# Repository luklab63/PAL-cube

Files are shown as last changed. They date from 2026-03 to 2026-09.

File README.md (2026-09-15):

# PAL V2 

## electronics 

* ESP32 C6 dev-module
* 2x SG90 servo moteurs 
* SH1106 0.94" OLED screen 
* power switch 
* small battery bank 
* used usb cable 
* PCB 
* 2 LEDs + 2x 220ohm resistors 

## The PCB 

it is a simple PCB that holds the ESP32 the battery connector and the screen and servo connectors. it is 70 x 60 mm. two 3mm LEDs 

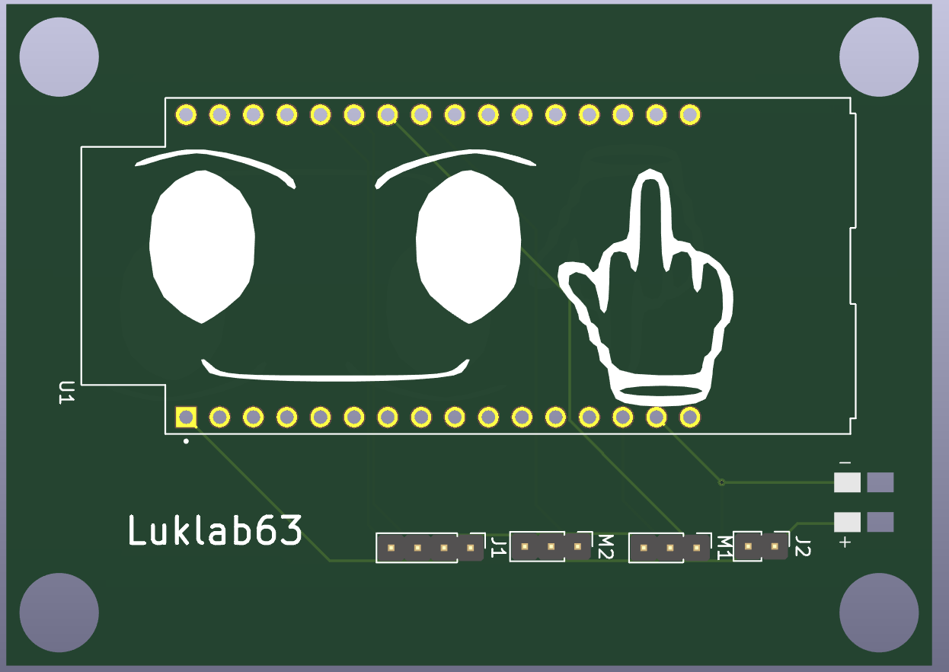
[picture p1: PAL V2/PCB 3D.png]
pcb
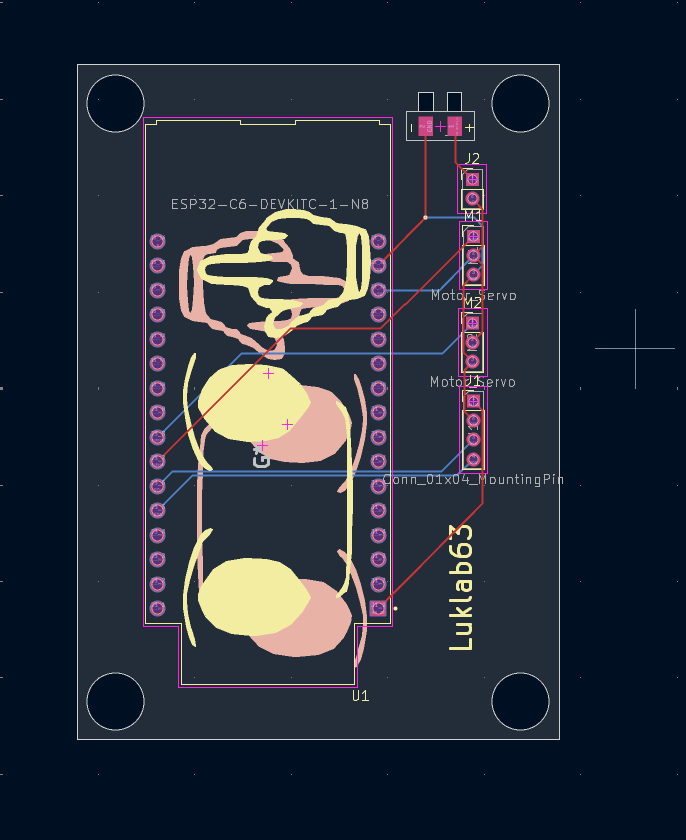
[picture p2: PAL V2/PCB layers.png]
PCB
 

## firmware

### APK

the apk was designed in MIT app inventor using the BLE library and by revers engineering the BLE-controller project on github.

the app is used to control the servo motors and the face that is shown
### The code 

the code is also based on the BLE-controller project however i have modified a lot to add the U2G8 library to control the screen

the faces are stored in the bitmap.h file. to get the bitmaps for each face you need to convert your image to XBM and than open it with a text editor 

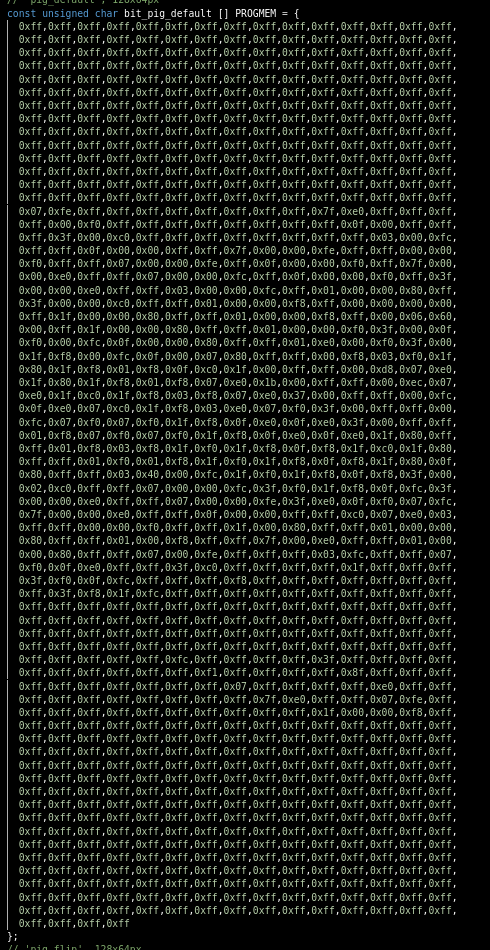
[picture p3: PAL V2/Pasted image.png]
XBM
 

## The shoulder mount and 3D prints
this mount is modeled for my shoulder, there are cutouts on the arms that rap around the shoulder to loop a custom made belt so the whole assembly is stable.the neck and head are screwed to this mount via some heatset inserts and the whole assembly is pretty stable once installed properly 

pictures and gifs coming soon.

the ESP-32 and PCB fit into a small boxed attached to the belt the power switch and LEDS will be visible? i will try to get some acrilic cut to fit as a lid for said box.

## final product 

the final product i intend to make is a shoulder mounted PAL that is battery powered. 

## funding required

i am pretty autonomous for electronics and coding however funding is needed for 3D printing filament and to print out the PCB.

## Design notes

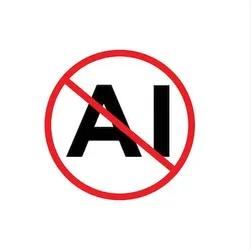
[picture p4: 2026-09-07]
PAL V2/no AI.png

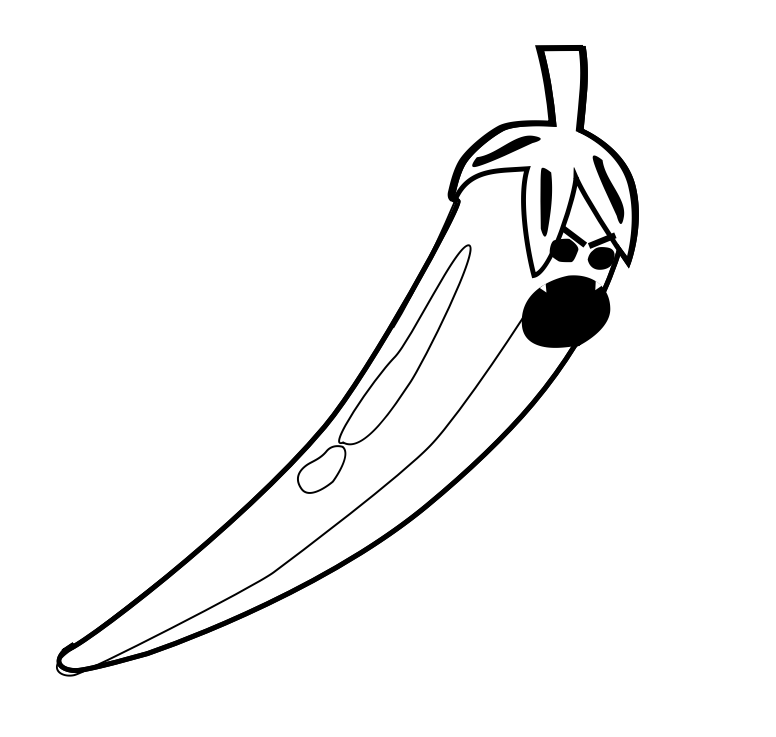
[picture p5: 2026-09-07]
PAL V2/dessin.png

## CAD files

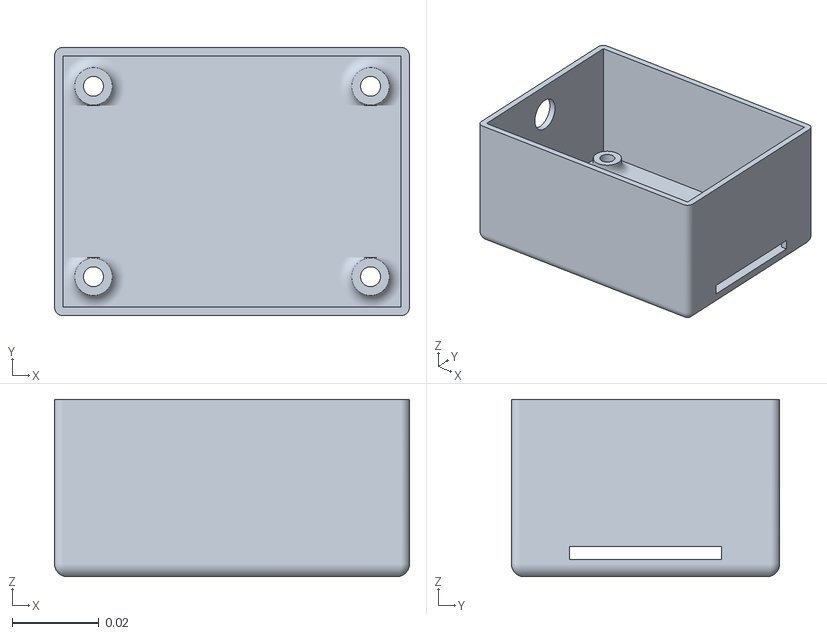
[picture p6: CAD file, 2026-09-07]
PAL V2/3D models/ESP box.stl
0.082 x 0.062 x 0.041

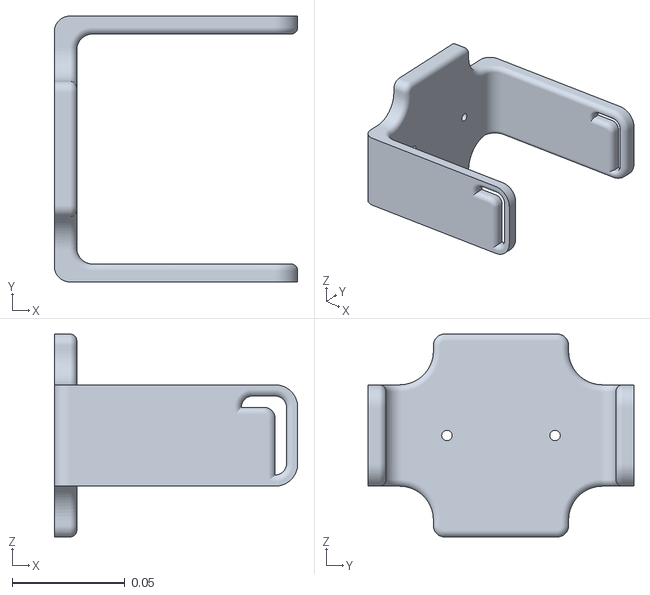
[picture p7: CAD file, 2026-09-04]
PAL V2/3D models/shoulder breket.stl
0.108 x 0.118 x 0.09

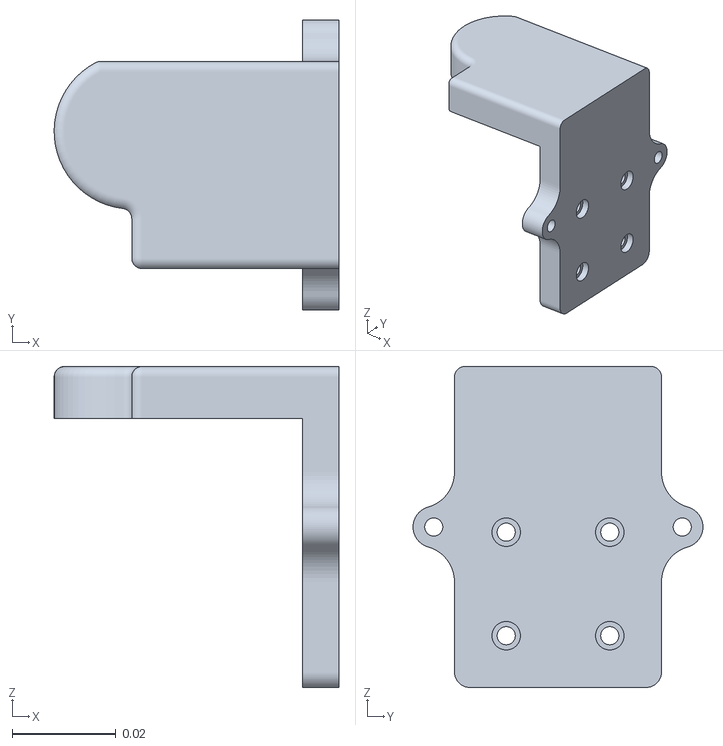
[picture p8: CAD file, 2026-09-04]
PAL V2/3D models/BASE P2.stl
0.055 x 0.056 x 0.062

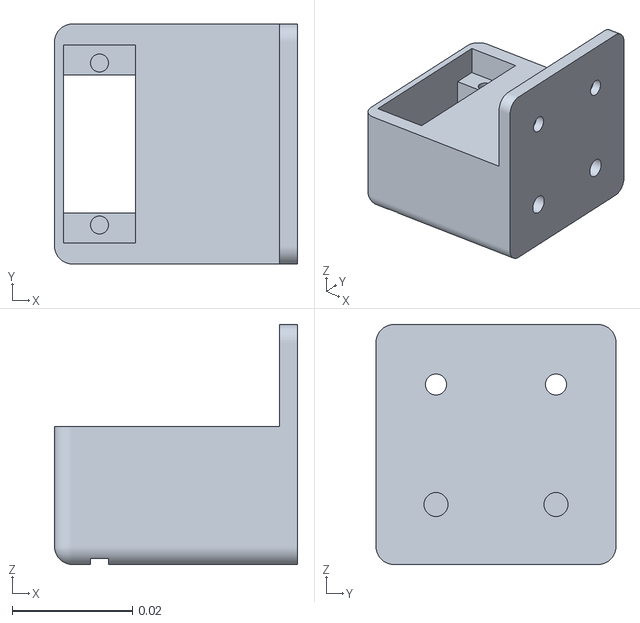
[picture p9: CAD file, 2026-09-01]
PAL V2/3D models/base.stl
0.0405 x 0.04 x 0.04

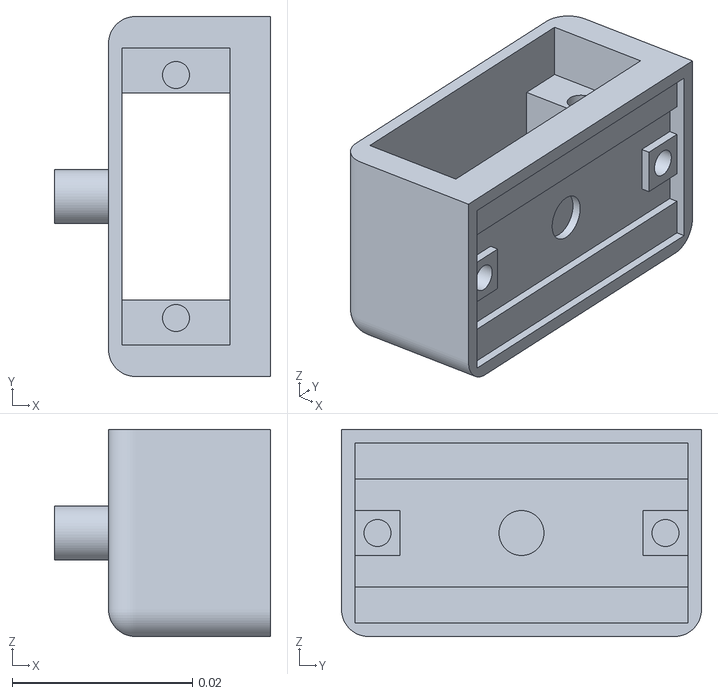
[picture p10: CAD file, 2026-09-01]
PAL V2/3D models/BRAS 1.stl
0.024 x 0.04 x 0.023

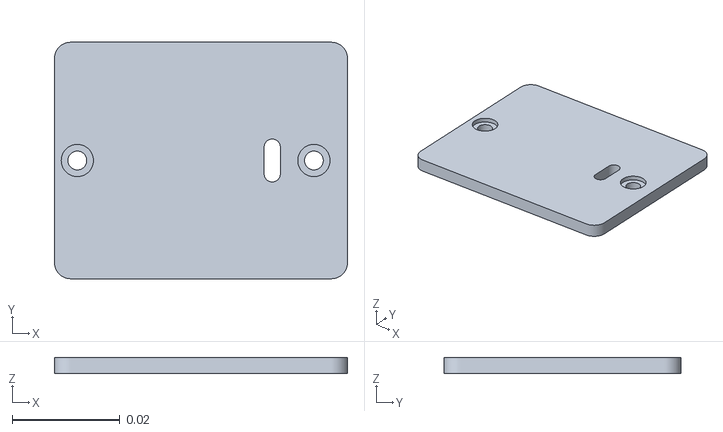
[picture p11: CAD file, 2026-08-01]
PAL V2/3D models/BACK PLATE .stl
0.0545 x 0.044 x 0.003

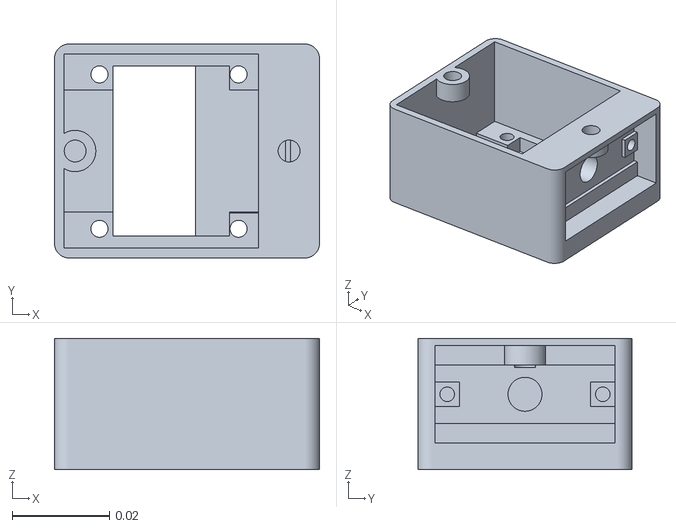
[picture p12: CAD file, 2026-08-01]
PAL V2/3D models/haid suport.stl
0.0545 x 0.044 x 0.027

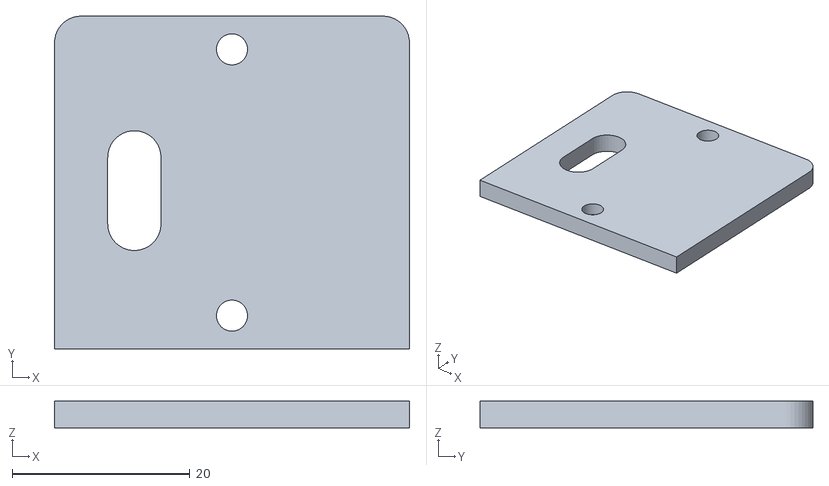
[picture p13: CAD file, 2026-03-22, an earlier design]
PAL V1/3D models/backplates/back pal case sans bat .step.STL
40.0 x 37.5 x 3.00

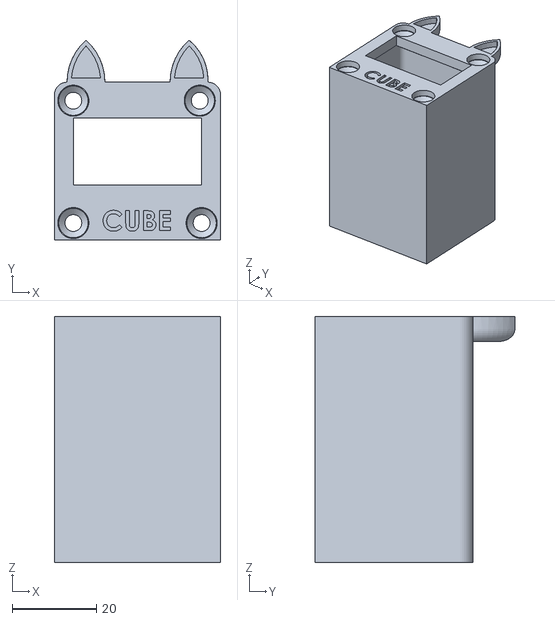
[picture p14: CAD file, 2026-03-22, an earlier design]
PAL V1/3D models/cat model/cat body.STL
39.5 x 47.5 x 58.5

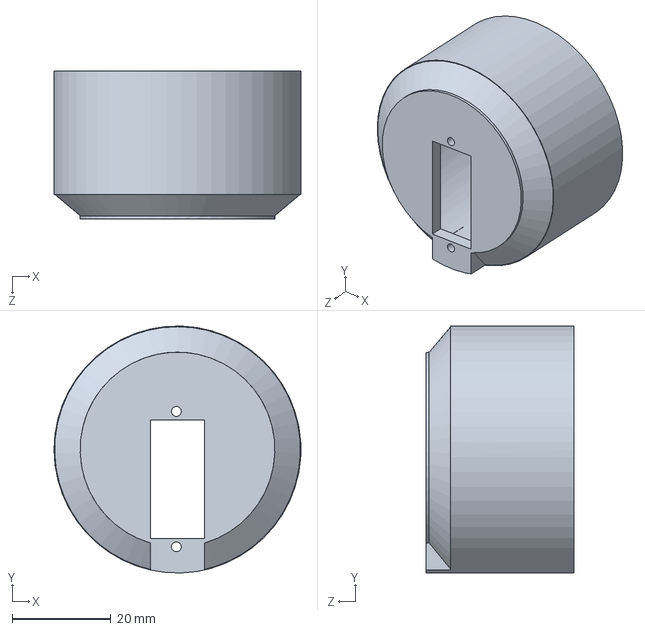
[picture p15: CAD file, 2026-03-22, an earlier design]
PAL V1/3D models/moving neck (WIP)/basse.SLDPRT
50.0 x 50.0 x 30.0 mm

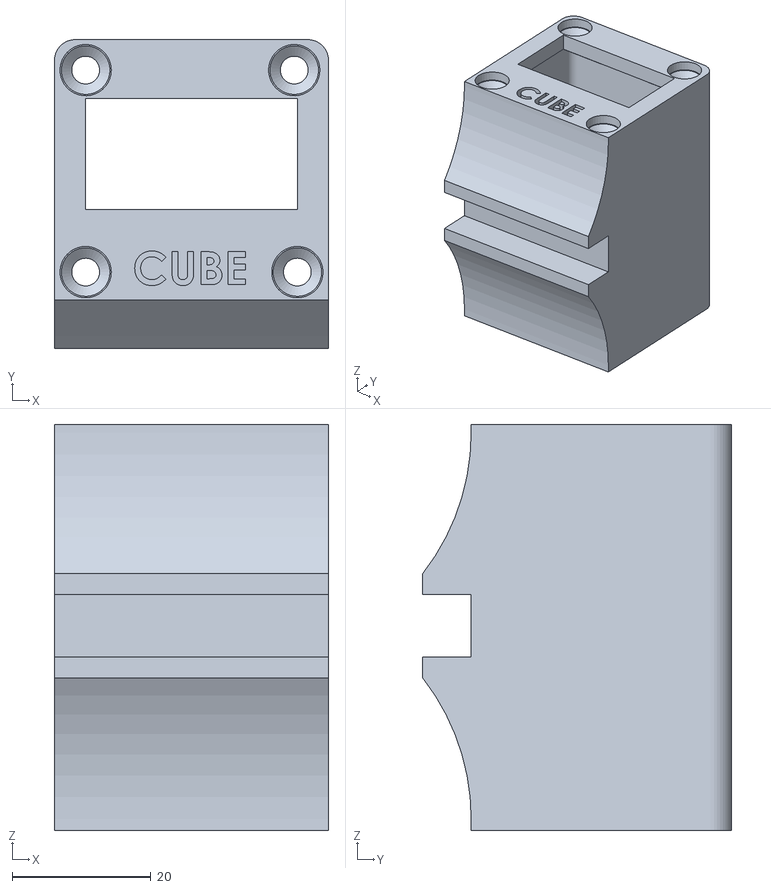
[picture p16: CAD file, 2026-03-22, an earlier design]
PAL V1/3D models/normal model/normal body computer rest .STL
39.5 x 44.5 x 58.5

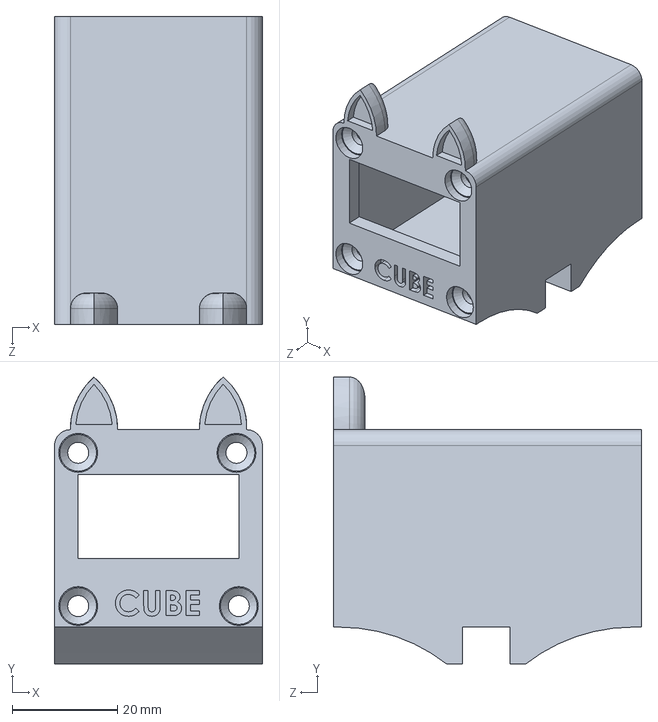
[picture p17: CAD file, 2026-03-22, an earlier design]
PAL V1/3D models/solidworks/cat body computer rest.SLDPRT
39.5 x 54.5 x 58.5 mm

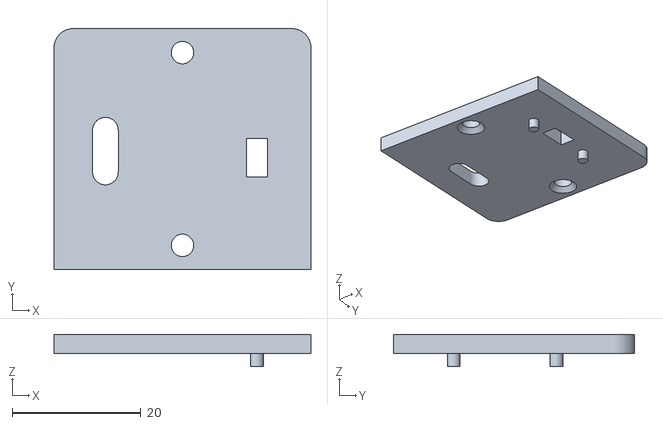
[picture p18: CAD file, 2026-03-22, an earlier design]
PAL V1/3D models/backplates/back pal case avec bat.step.STL
40.0 x 37.5 x 5.00

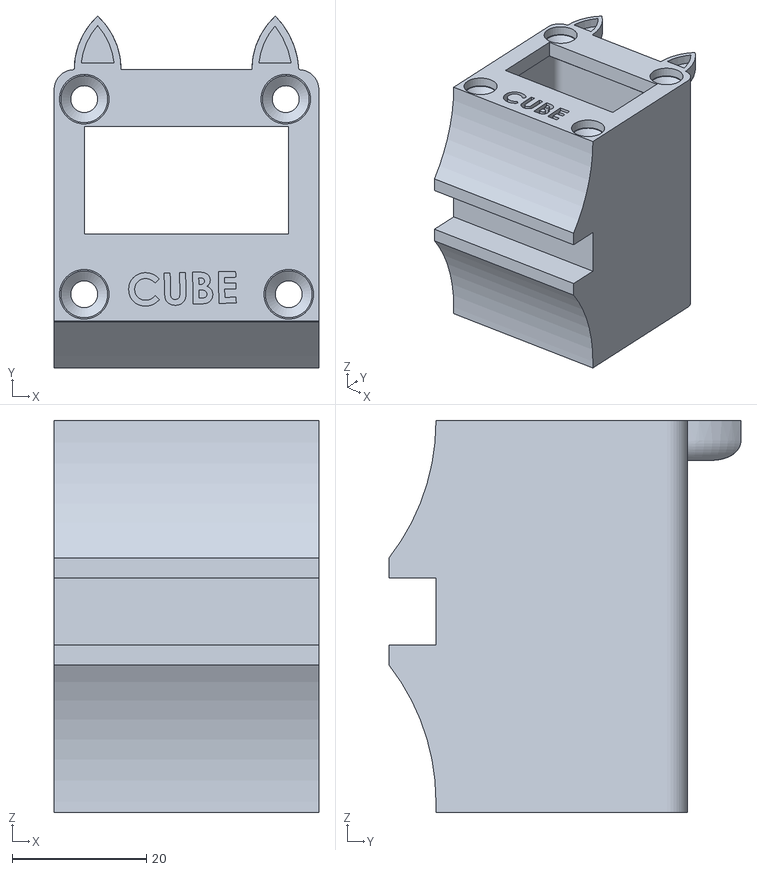
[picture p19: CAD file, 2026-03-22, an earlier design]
PAL V1/3D models/cat model/front pal case cat SLDPRT.STL
39.5 x 52.5 x 58.5

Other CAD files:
PAL V1/3D models/normal model/normal body.STL
PAL V1/3D models/solidworks/front pal case.step.SLDPRT
PAL V1/3D models/solidworks/back pal case.step.SLDPRT
PAL V1/3D models/solidworks/front pal case.step

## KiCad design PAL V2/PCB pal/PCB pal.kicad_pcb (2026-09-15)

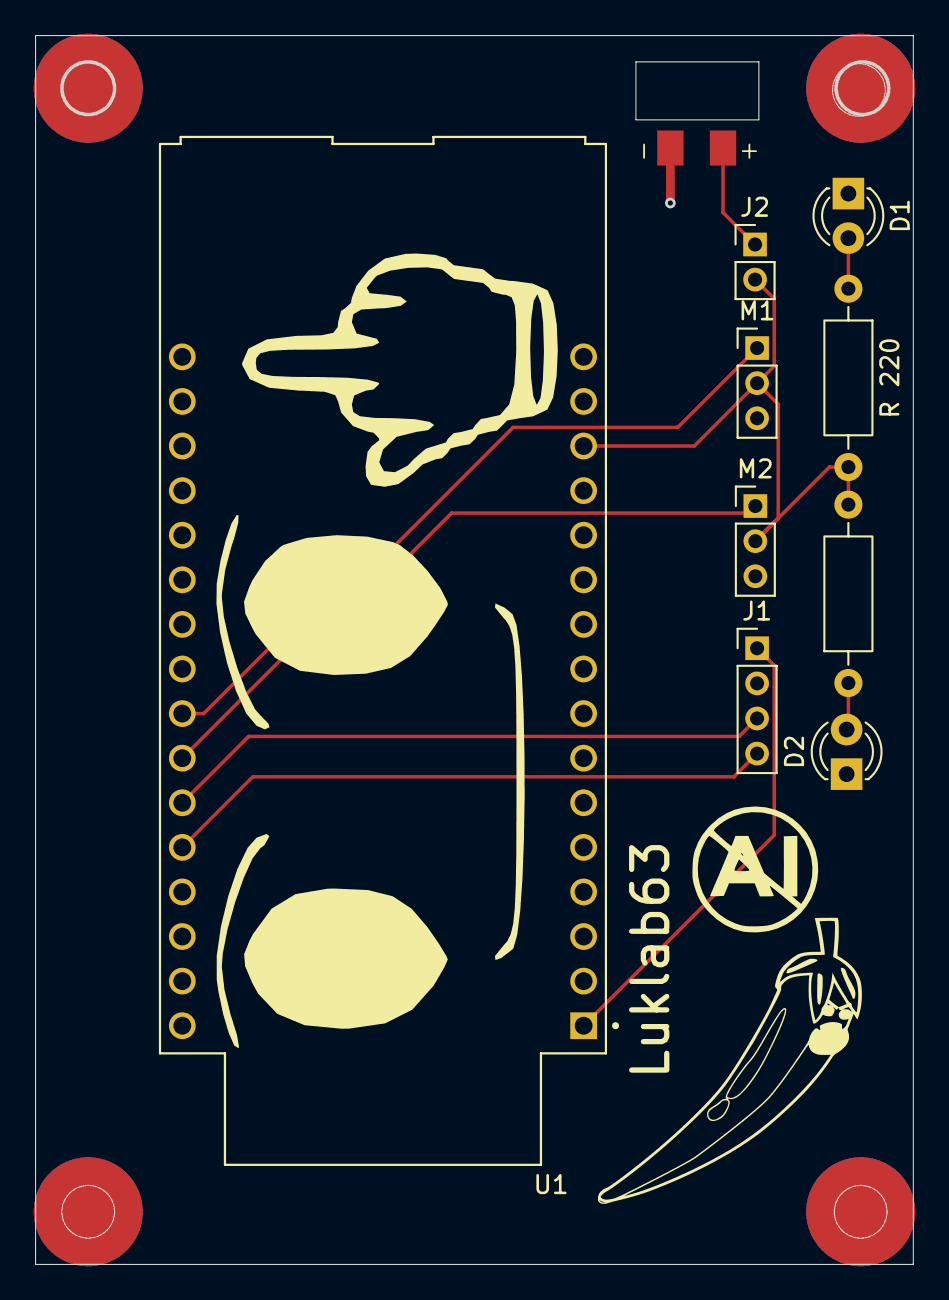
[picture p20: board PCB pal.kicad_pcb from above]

Board: 2 copper layers, 50.0 x 70.0 mm, 10 parts (0 on the bottom side), 10 nets.

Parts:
D1, D2: LED; LED_D3.0mm
J1: Conn_01x04_MountingPin; PinHeader_1x04_P2.00mm_Vertical
J2: Conn_01x02; PinHeader_1x02_P2.00mm_Vertical
J3: Conn_01x02; BatteryTERMINAL
M1, M2: Motor_Servo; PinHeader_1x03_P2.00mm_Vertical
R 220, R 220#2: R 220; R_Axial_DIN0207_L6.3mm_D2.5mm_P10.16mm_Horizontal
U1: ESP32-C6-DEVKITC-1-N8; MODULE_ESP32-C6-DEVKITC-1-N8

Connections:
+3.3V: J1.1, U1.J1_1 (ESP_3V3)
+5V: J2.2, M1.2 (+), M2.2 (+), R 220.2, R 220#2.2, U1.J1_14 (VCC_5V)
/SCL: J1.3, U1.J3_6 (GPIO22)
/SDA: J1.4, U1.J3_5 (GPIO23)
/SERVO1: M1.1 (PWM), U1.J3_7 (GPIO21)
/SERVO2: M2.1 (PWM), U1.J3_8 (GPIO20)
GND: D1.1 (K), D2.1 (K), J1.2, J3.2, M1.3 (-), M2.3 (-), U1.J1_15 (GND_J1_15)
unnamed: D1.2 (A), R 220.1
unnamed: D2.2 (A), R 220#2.1
unnamed: J2.1, J3.1

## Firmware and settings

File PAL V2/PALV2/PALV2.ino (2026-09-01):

/*
  Based on Neil Kolban example for IDF: https://github.com/nkolban/esp32-snippets/blob/master/cpp_utils/tests/BLE%20Tests/SampleNotify.cpp
  Ported to Arduino ESP32 by Evandro Copercini
  updated by chegewara and MoThunderz
*/
#include <BLEDevice.h>
#include <BLEServer.h>
#include <BLEUtils.h>
#include <BLE2902.h>
#include <ESP32Servo.h>

#include "bitmap.hpp"
#include <U8g2lib.h>
#include <Wire.h>
U8G2_SH1106_128X64_NONAME_F_HW_I2C u8g2(U8G2_R0, /* reset=*/ U8X8_PIN_NONE);

BLEServer* pServer = NULL;
BLECharacteristic* pCharacteristic = NULL;
BLECharacteristic* pCharacteristic_2 = NULL;
BLECharacteristic* pCharacteristic_3 = NULL;
BLECharacteristic* pCharacteristic_4 = NULL;
BLEDescriptor *pDescr;
BLE2902 *pBLE2902;

bool deviceConnected = false;
bool oldDeviceConnected = false;
uint32_t value = 0;
int face = 1;

// See the following for generating UUIDs:
// https://www.uuidgenerator.net/

#define SERVICE_UUID        "4fafc201-1fb5-459e-8fcc-c5c9c331914b"
#define CHAR1_UUID          "beb5483e-36e1-4688-b7f5-ea07361b26a8"
#define CHAR2_UUID          "e3223119-9445-4e96-a4a1-85358c4046a2"
#define CHAR3_UUID          "4e854d58-2ca4-448d-b1cb-6481e19567e8"
#define CHAR4_UUID          "6c6dc165-eb19-41dd-85d0-7cd7d2b64394"

#define SERVO_PIN1 21 // ESP32 pin GPIO26 connected to servo motor
#define SERVO_PIN2 20 // ESP32 pin GPIO26 connected to servo motor
Servo servoMotor1;
Servo servoMotor2;

class MyServerCallbacks: public BLEServerCallbacks {
    void onConnect(BLEServer* pServer) {
      deviceConnected = true;
    };

    void onDisconnect(BLEServer* pServer) {
      deviceConnected = false;
    }
};

class CharacteristicCallBack: public BLECharacteristicCallbacks {
  void onWrite(BLECharacteristic *pChar) override { 
    String value_string = pChar->getValue();
    int value_int = value_string.toInt();
    
    // Identify which characteristic was written to
    String charName = "Unknown";
    
    if (pChar == pCharacteristic_2) {
      charName = "Characteristic 2";
      servoMotor1.write(90 + value_int) ;

    } else if (pChar == pCharacteristic_3) {
      charName = "Characteristic 3";
      servoMotor2.write(90 + value_int) ;
      
    } else if (pChar == pCharacteristic_4) {
      charName = "Characteristic 4";
      face = value_int;
      Serial.println(face);
    }

    Serial.println(charName + " written with value: " + String(value_int));
    
  }
};

void setup() {
  Serial.begin(115200);

  u8g2.begin();
  u8g2.enableUTF8Print(); //nécessaire pour écrire des caractères accentués
  u8g2.setColorIndex(0);

  servoMotor1.attach(SERVO_PIN1);
  servoMotor2.attach(SERVO_PIN2);
  // Create the BLE Device
  BLEDevice::init("ESP32");

  // Create the BLE Server
  pServer = BLEDevice::createServer();
  pServer->setCallbacks(new MyServerCallbacks());

  // Create the BLE Service
  BLEService *pService = pServer->createService(SERVICE_UUID);

  // Create a BLE Characteristic
  pCharacteristic = pService->createCharacteristic(
                      CHAR1_UUID,
                      BLECharacteristic::PROPERTY_NOTIFY
                    );                   

  pCharacteristic_2 = pService->createCharacteristic(
                      CHAR2_UUID,
                      BLECharacteristic::PROPERTY_READ   |
                      BLECharacteristic::PROPERTY_WRITE  
                    );  

  pCharacteristic_3 = pService->createCharacteristic(
                      CHAR3_UUID,
                      BLECharacteristic::PROPERTY_READ   |
                      BLECharacteristic::PROPERTY_WRITE  
                    );  

  pCharacteristic_4 = pService->createCharacteristic(
                      CHAR4_UUID,
                      BLECharacteristic::PROPERTY_READ   |
                      BLECharacteristic::PROPERTY_WRITE  
                    );

  // Create a BLE Descriptor
  
  pDescr = new BLEDescriptor((uint16_t)0x2901);
  pDescr->setValue("A very interesting variable");
  pCharacteristic->addDescriptor(pDescr);
  
  pBLE2902 = new BLE2902();
  pBLE2902->setNotifications(true);
  
  // Add all Descriptors here
  pCharacteristic->addDescriptor(pBLE2902);
  pCharacteristic_2->addDescriptor(new BLE2902());
  pCharacteristic_3->addDescriptor(new BLE2902());
  pCharacteristic_4->addDescriptor(new BLE2902());

  // After defining the desriptors, set the callback functions
  pCharacteristic_2->setCallbacks(new CharacteristicCallBack());
  pCharacteristic_3->setCallbacks(new CharacteristicCallBack());
  pCharacteristic_4->setCallbacks(new CharacteristicCallBack());
  // Start the service
  pService->start();

  // Start advertising
  BLEAdvertising *pAdvertising = BLEDevice::getAdvertising();
  pAdvertising->addServiceUUID(SERVICE_UUID);
  pAdvertising->setScanResponse(false);
  pAdvertising->setMinPreferred(0x0);  // set value to 0x00 to not advertise this parameter
  BLEDevice::startAdvertising();
  Serial.println("Waiting a client connection to notify...");
}

void loop() {
  
  // notify changed value
  if (deviceConnected) {
      pCharacteristic->setValue(value);
      pCharacteristic->notify();
      value++;
      delay(1000);
  }
  // disconnecting
  if (!deviceConnected && oldDeviceConnected) {
      delay(500); // give the bluetooth stack the chance to get things ready
      pServer->startAdvertising(); // restart advertising
      Serial.println("start advertising");
      oldDeviceConnected = deviceConnected;
  }
  // connecting
  if (deviceConnected && !oldDeviceConnected) {
      // do stuff here on connecting
      oldDeviceConnected = deviceConnected;
  }
  
  if ()
    if (face == 0){
      u8g2.clearBuffer(); // on efface ce qui se trouve déjà dans le buffer
      u8g2.drawXBMP( 0, 0, 128, 64, fuck_face); // position, largeur, hauteur
      u8g2.sendBuffer();  // l'image qu'on vient de construire est affichée à l'écran
    } else if (face == 1){
      u8g2.clearBuffer(); // on efface ce qui se trouve déjà dans le buffer
      u8g2.drawXBMP( 0, 0, 128, 64, default_face); // position, largeur, hauteur
      u8g2.sendBuffer();  // l'image qu'on vient de construire est affichée à l'écran
    } else if (face == 2){
      u8g2.clearBuffer(); // on efface ce qui se trouve déjà dans le buffer
      u8g2.drawXBMP( 0, 0, 128, 64, angy_face); // position, largeur, hauteur
      u8g2.sendBuffer();  // l'image qu'on vient de construire est affichée à l'écran
    } else if (face == 3){
      u8g2.clearBuffer(); // on efface ce qui se trouve déjà dans le buffer
      u8g2.drawXBMP( 0, 0, 128, 64, sleep_face); // position, largeur, hauteur
      u8g2.sendBuffer();  // l'image qu'on vient de construire est affichée à l'écran
    }

}

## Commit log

2026-03-22 3D model
    [back pal case avec bat.step.STL, back pal case sans bat .step.STL, back pal case.step.SLDPRT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]
2026-03-22 better 3D models
    [back pal case avec bat.step.STL, back pal case sans bat .step.STL, back pal case.step.SLDPRT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]
2026-07-23 pal V1
    [back pal case avec bat.step.STL, back pal case sans bat .step.STL, back pal case.step.SLDPRT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]
2026-08-01 head suport created
    [BACK PLATE .stl, haid suport.stl]
2026-09-01 fixed oopsie
    [BASE P2.stl, BRAS 1.stl, PCB pal.kicad_pcb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]
2026-09-04 New PCB changes
    [PCB pal.kicad_pcb, PCB pal.kicad_sch]
2026-09-04 readme test
    [BACK PLATE .stl, BASE P2.stl, BRAS 1.stl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]
2026-09-04 shoulder mount
    [BASE P2.stl, PCB pal.kicad_pcb, shoulder breket.stl]
2026-09-07 ESP BOX+ PCB
    [ESP box.stl, PCB pal.kicad_pcb]
2026-09-15 PCB finished and sent to print
    [PCB pal-B_Cu.gbr, PCB pal-B_Mask.gbr, PCB pal-B_Paste.gbr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]
2026-10-11 PCB EDIT + STEP FILES
